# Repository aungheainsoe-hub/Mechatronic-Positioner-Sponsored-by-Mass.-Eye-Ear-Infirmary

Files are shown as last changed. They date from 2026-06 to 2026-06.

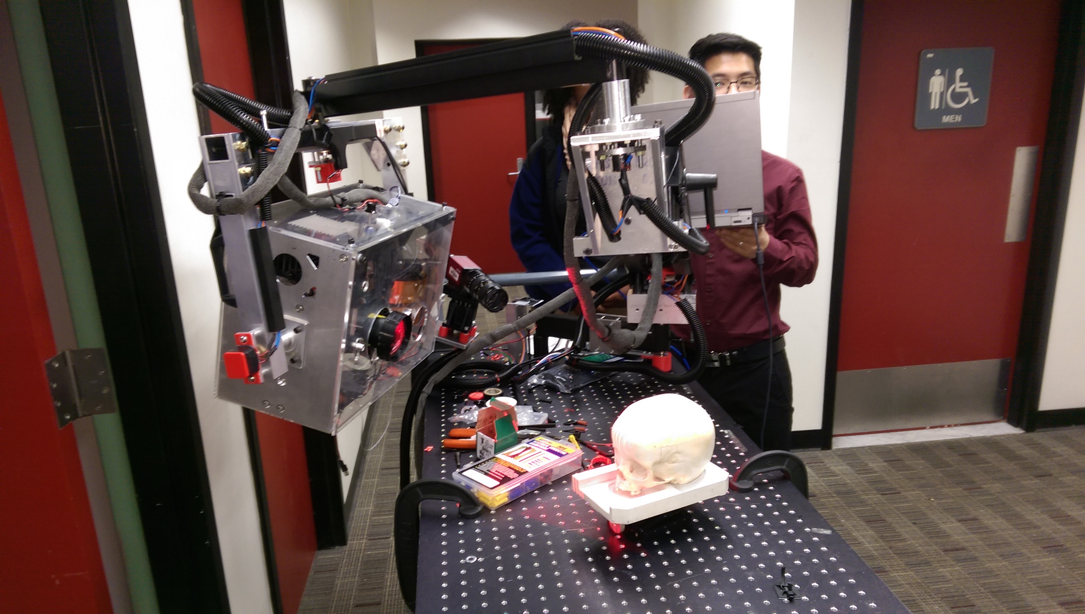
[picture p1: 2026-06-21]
IMAG0439.jpg

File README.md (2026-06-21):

# Mechatronic-Positioner-Sponsored-by-Mass.-Eye-Ear-Infirmary
Designing to implement a new generation of Mechatronic positioning system for a shape measurements device (fringe projector) used for medical and industrial applications.

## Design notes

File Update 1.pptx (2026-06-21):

## Repackaging of Fringe Projector

Design Group 1
ME 4320

## List of components

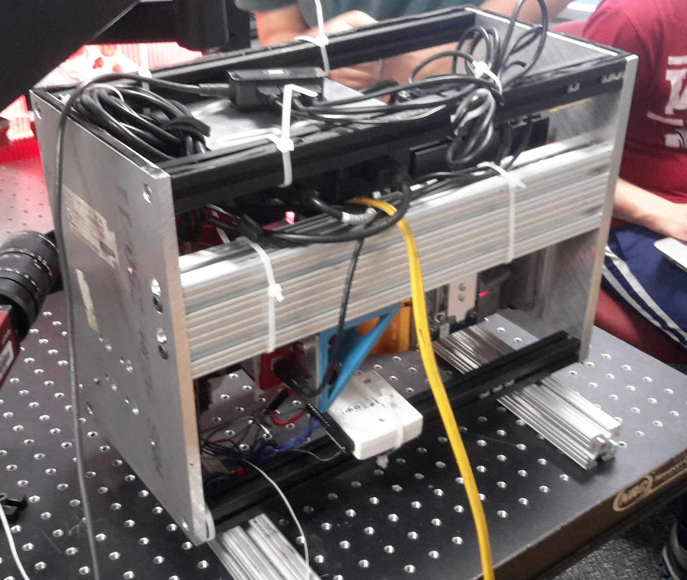
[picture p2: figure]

- Side Panels Al 6061 (8”x12”x.375”) = 3.51 lb x 2 = 7.02 lb
- Beam Al 8020 Double wide (1.5”x3”x16”) = 3.23 lb
- Black 80/20 Al frame beams (1”x1”x16”) = 1.37 lb x 4 = 5.48 lb
- Cables, power adapters, wiring = est.6 lb
- Fringe Projector (Structured light projection package = 1800 g = 3.97 lb
Total weight = approx. 26.8 lb
- Camera = 250 g =.55 lb

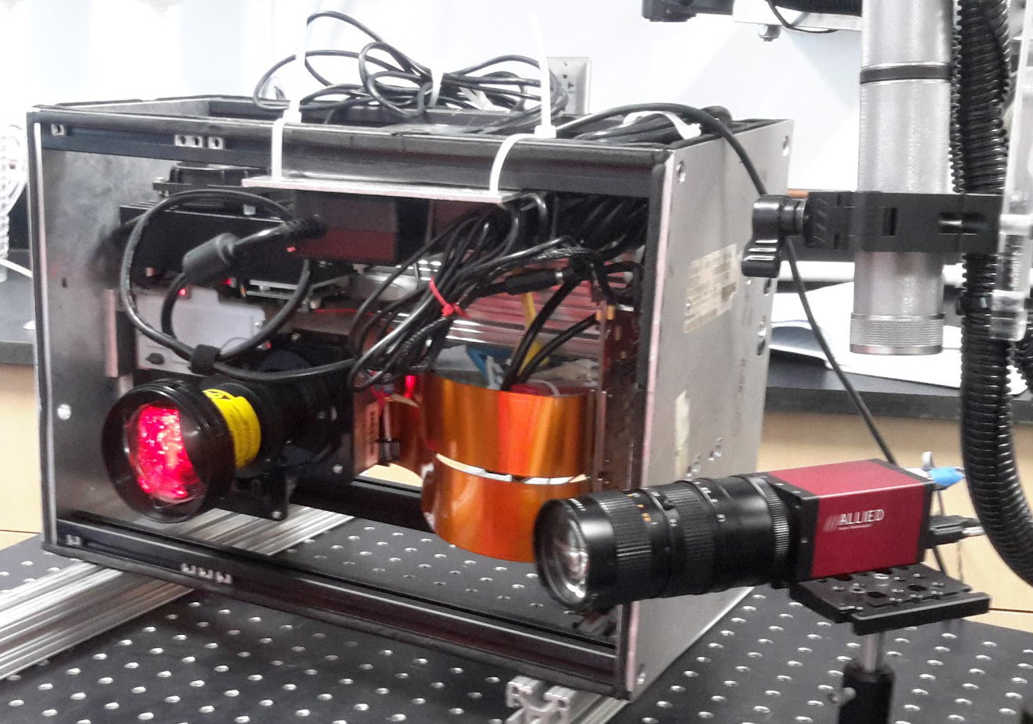
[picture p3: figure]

## Potential Layout Changes

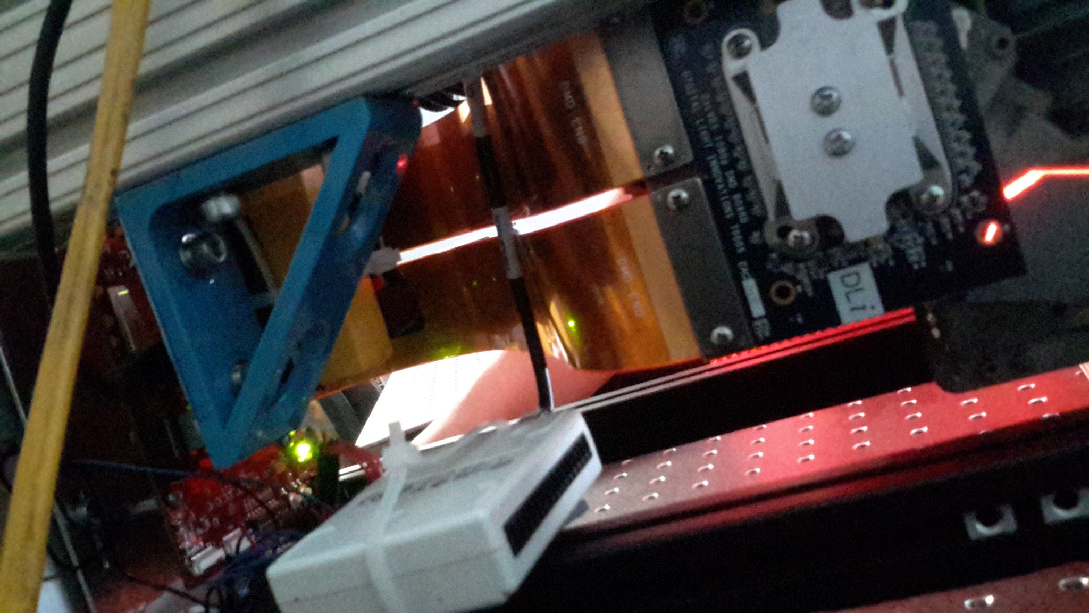
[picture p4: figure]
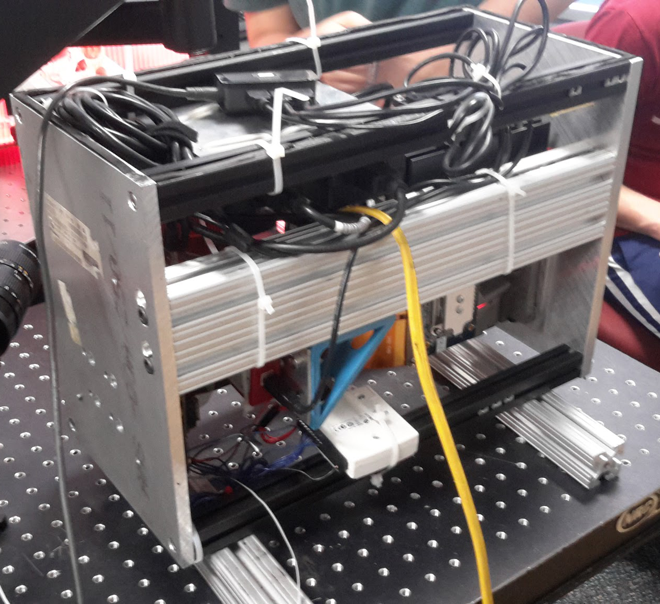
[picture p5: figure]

Weight Reduction
- Thinner plates/Milled plates: up to 4.68 lb
- Remove double wide 80/20: 3.23 lb
- Replace double wide 80/20 with 1” square beam: 1.86 lb

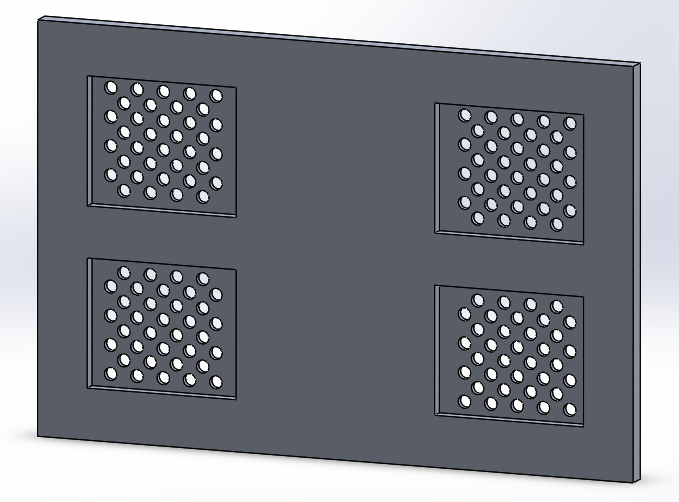
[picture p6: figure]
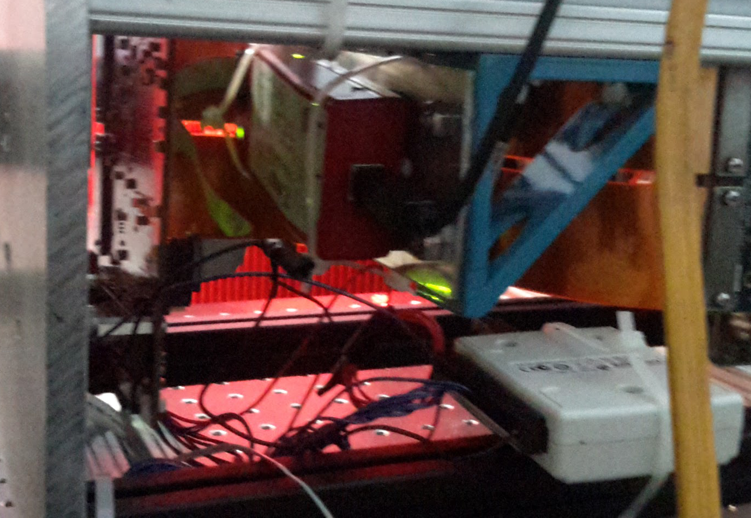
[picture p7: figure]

## Cable Management

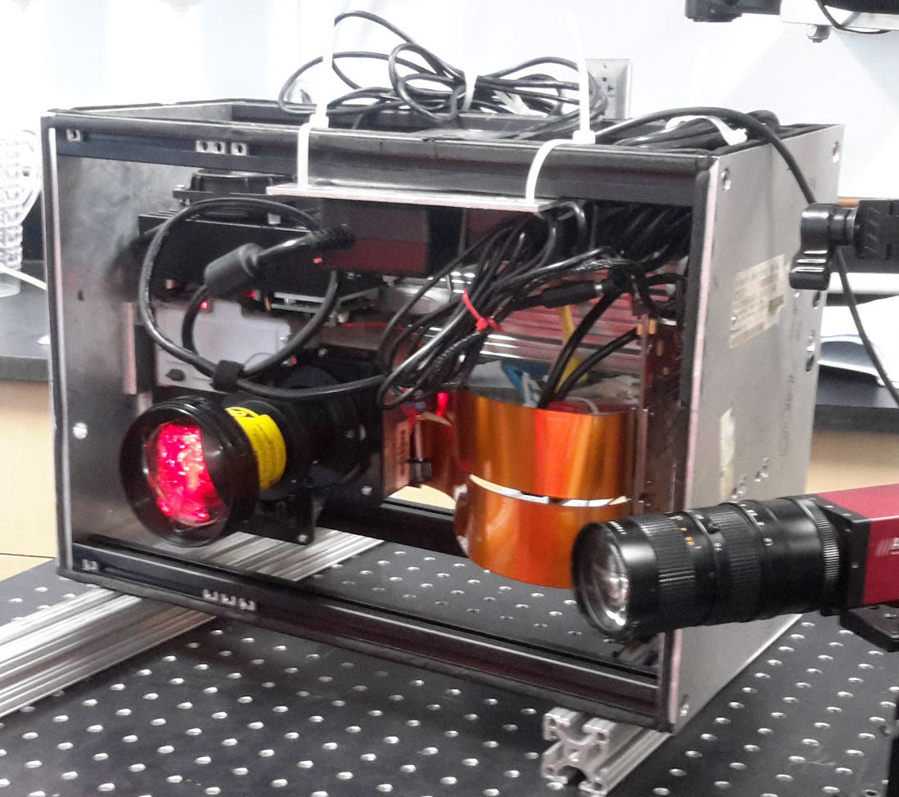
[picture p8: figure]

Weight Reduction
- Removing/relocating cables: up to 5 lb at end effector

## Positioning Camera

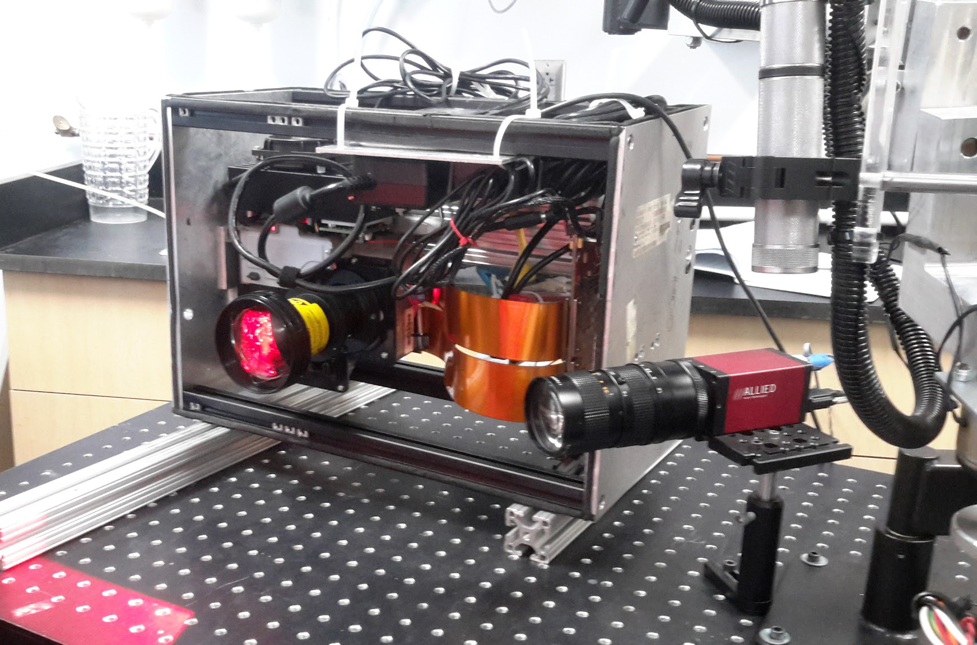
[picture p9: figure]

Weight Reduction
- Adds weight from camera: .55 lb

## Potential Added Weight

- Handles: .43 lb per handle
- Acrylic casing
  - Top and bottom panels: 2.18 lb per panel .375 thickness, 1.09 lb per panel 3/16” thickness
  - Back panel: 3.27 lb for .325” thickness, 1.63 lb for 3/16” thickness,
- Camera: .55 lb
- Sensors: unknown at this point

## Overall Estimates

- Expect to reduce weight by approximately 5 pounds
- Optimistically, 7-8 pounds

## Resources

WPI paper on the original packaging - https://www.wpi.edu/Pubs/ETD/Available/etd-082611-133113/unrestricted/Zervas.pdf
Steel handle used - http://www.knobdeals.com/product/391/knob-deals-1110-3-12quot-89mm-steel-bar-pull-satin-nickel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

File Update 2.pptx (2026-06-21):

## UPDATE

Design & Analysis 1

## Updates From Yesterday

- After changing the plates to 1/8" Garolite G-10 Only reduced the weight of the frame by 4lbs
- Wiring can be held adjacent to the C-bracket as seen from Design & Analysis #2
- At this point we are not sure how easily manufacture the material is and believe we should proceed with the current aluminum and polycarbonate set up

## Angle and Arm Length

- The angle α between the camera and projector can be calculated using sine law
- The angle β can either be read directly off of the mounting plate
- Camera support arm should be approximately 27.5” based off of our calculation of D.cp
- Allows for a maximum angle of 45 degrees

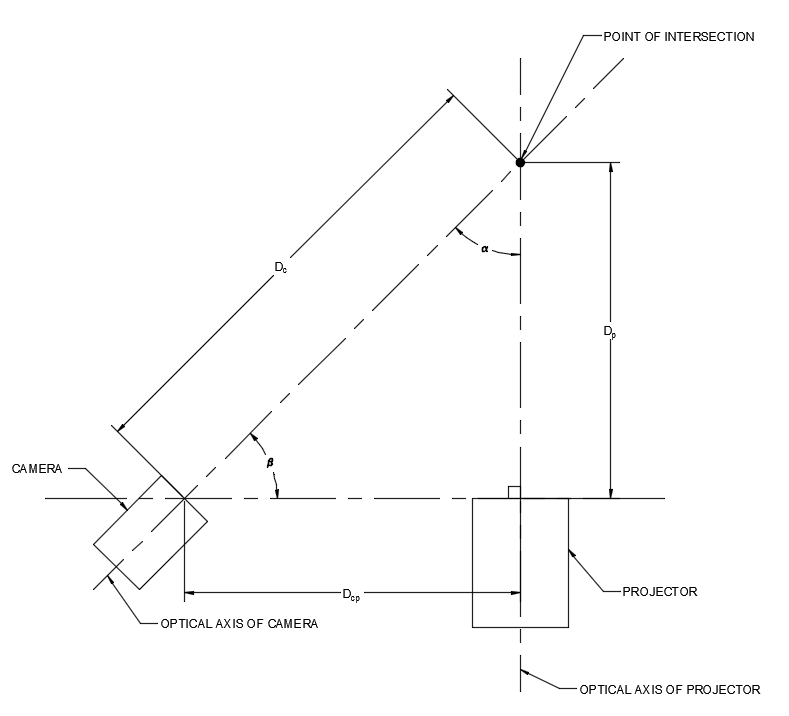
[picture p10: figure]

## Future Work

- Add Laser pointer into the assembly
- Finalize Connection Points to Arm
- Finalize housings for mini-DAQ box and Red box connecting to the DLP board
- Mount Distance Sensor

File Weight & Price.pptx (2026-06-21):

## Design & Analysis #1

## Weight of Components

QTY | Component | Weight (kg)
1 | Side Plate - Projector Side | 0.99
1 | Side Plate - Board Side | 0.73
1 | Top Plate | 0.32
1 | Bottom Plate | 0.33
1 | Fan | 0.01
1 | Fringe Projector & Board | 1.8
4 | 80/20 Support Beams | 1.24
1 | Camera Support Beam | 0.56
1 | Front Plate | 0.49

## Weight of Components: Continued

QTY | Component | Weight (kg)
1 | Camera | 0.25
1 | Lens | ~0.45
1 | Pro1 Manual Angle | 0.29
2 | Linear Carriage | Not Listed
2 | Hand Brake | Not Listed
1 | Mounting Plate | 0.14
N/A | Wiring & MISC | ~2.75
2 | Handes | Not Listed
Total | | 10.35 (~22.82-lbs)

## Price of Components

Component | Price (USD $)
Pro1 | $318
Mounting Plate | Part of Current Configuration
Camera Mounting Arm | $12.85
Handles | $12.80
Linear Carriage | $92.32
Hand Brakes | $21.54
Sticker Ruler | $10.56
80/20 Support Beams | Part of current configuration
Aluminum Sheets | $51.82

## Price of Components: Continued

Component | Price (USD $)
Poly Carbonate Sheet | $115.46
Total | $635.35

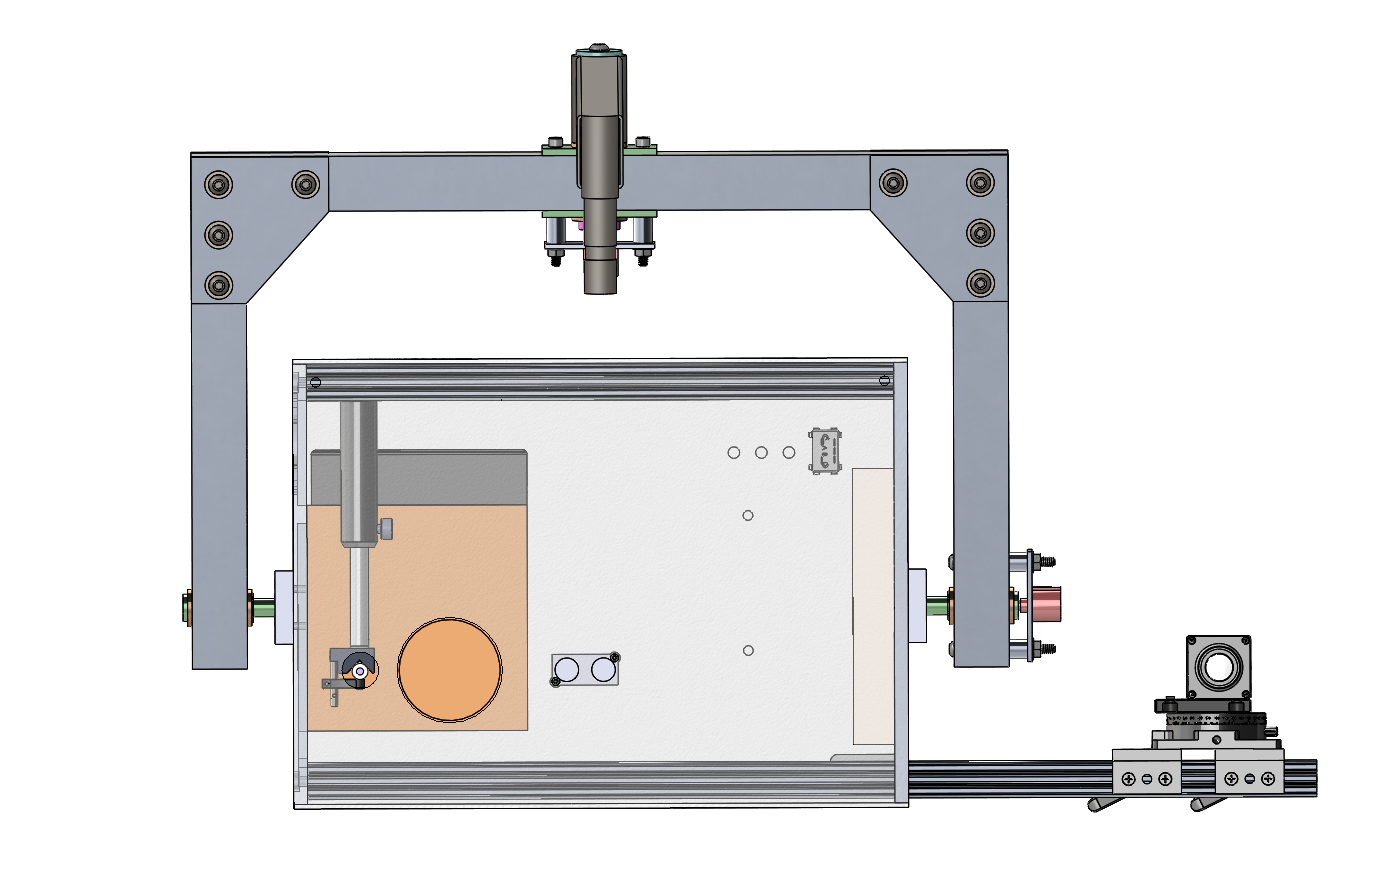
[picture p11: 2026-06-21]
Projector_Airflow.PNG

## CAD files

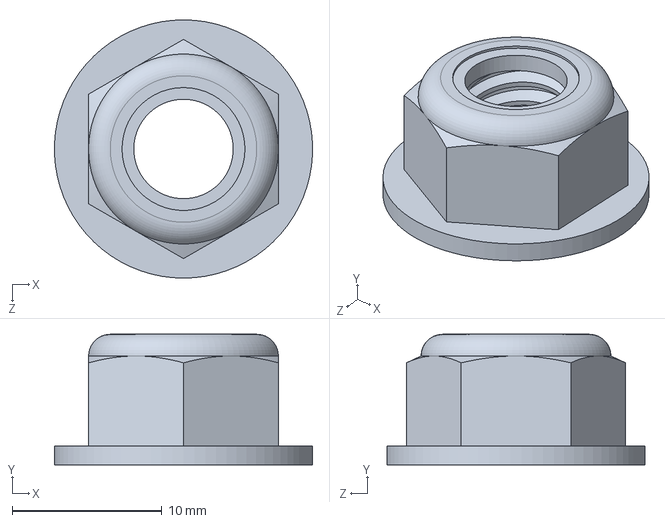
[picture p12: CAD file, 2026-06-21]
MM_92018A320_0.3125-18_Flanged-Locknut.SLDPRT
17.3 x 8.73 x 17.3 mm

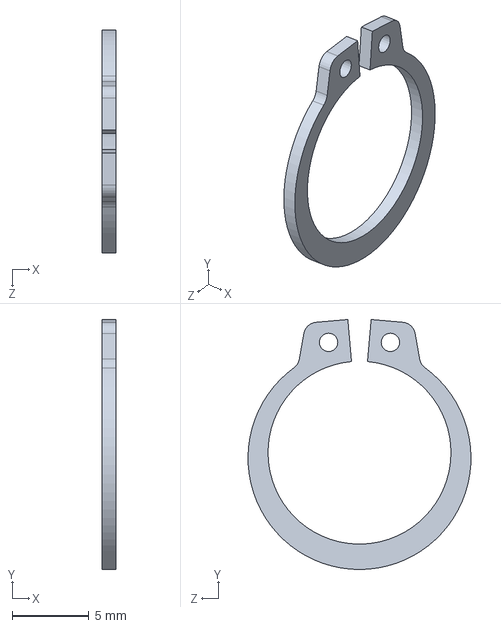
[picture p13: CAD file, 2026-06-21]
MM_96363A553_0.5in_External-Retaining-Ring.SLDPRT
0.889 x 16.2 x 14.5 mm

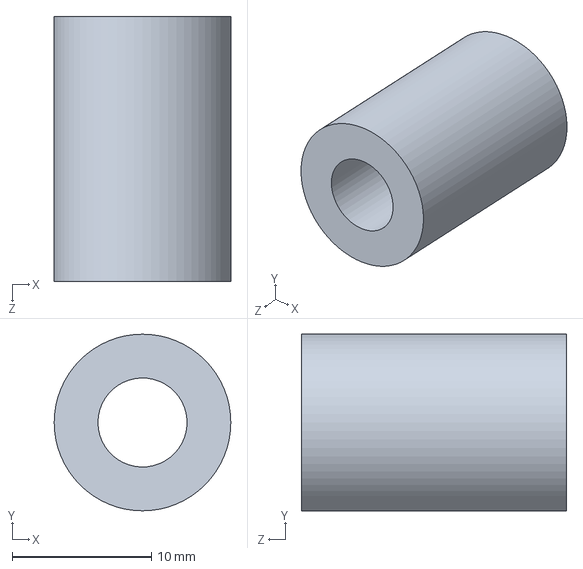
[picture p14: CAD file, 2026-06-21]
MM_92510A767_0.252IDx0.5ODx0.75L_AL-Spacer_Round.SLDPRT
12.7 x 12.7 x 19.1 mm

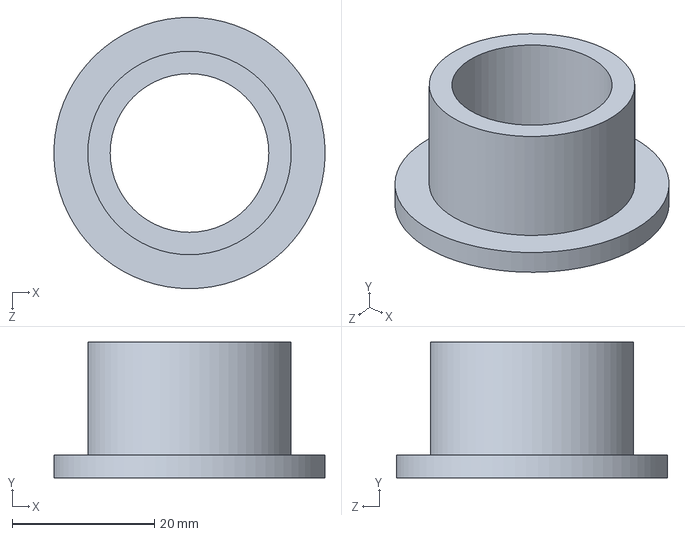
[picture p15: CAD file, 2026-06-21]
MM_6338K479_0.875IDx1.125ODx0.75L_Bushing.SLDPRT
38.1 x 19.1 x 38.1 mm

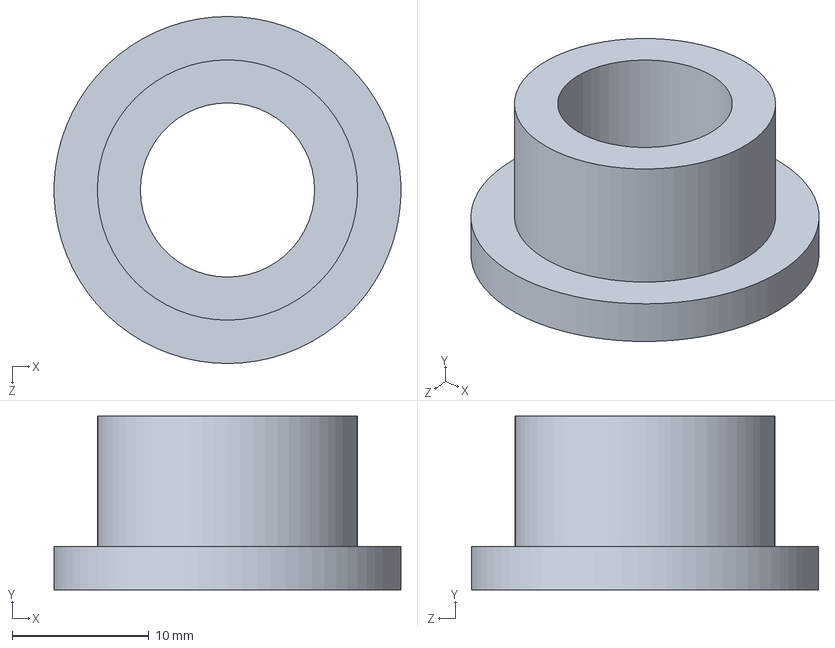
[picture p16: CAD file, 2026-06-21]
MM_6338K422_0.502IDx0.75ODx0.5L_Flanged-Sleeve-Bushing.SLDPRT
25.4 x 12.7 x 25.4 mm

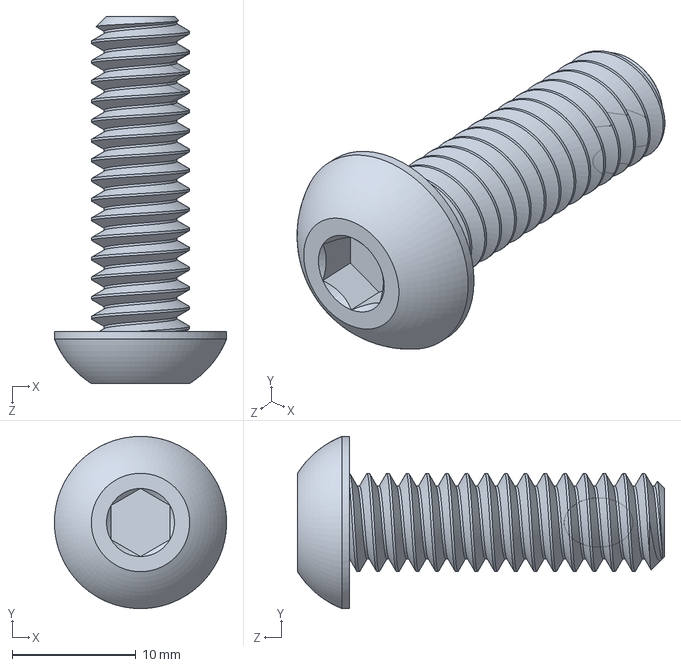
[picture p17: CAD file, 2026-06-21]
MM_93310A583_0.3125-18x1L_Thread-Locking_Button-Head.SLDPRT
13.9 x 13.9 x 29.6 mm

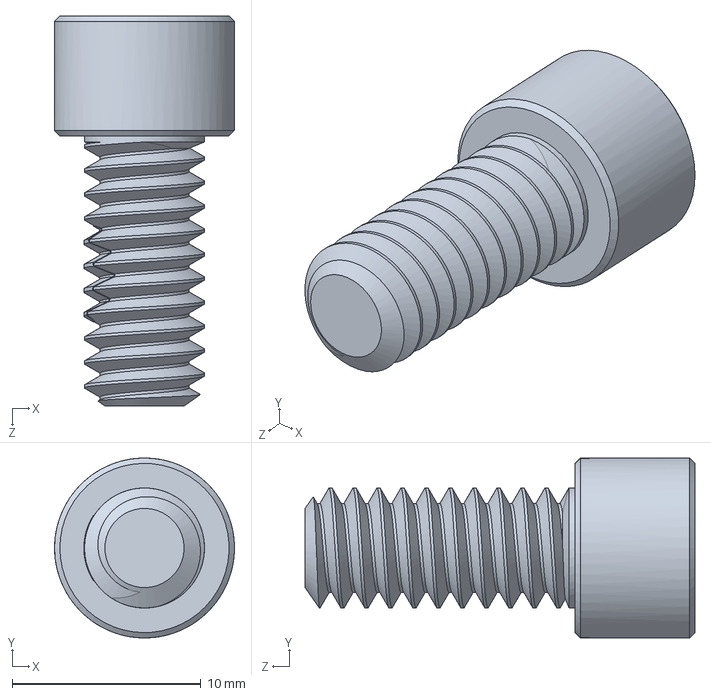
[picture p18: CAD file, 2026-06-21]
MM_91205A538_0.25-20x0.5625_Thread-Locking_Socket-Cap.SLDPRT
9.53 x 9.52 x 20.6 mm

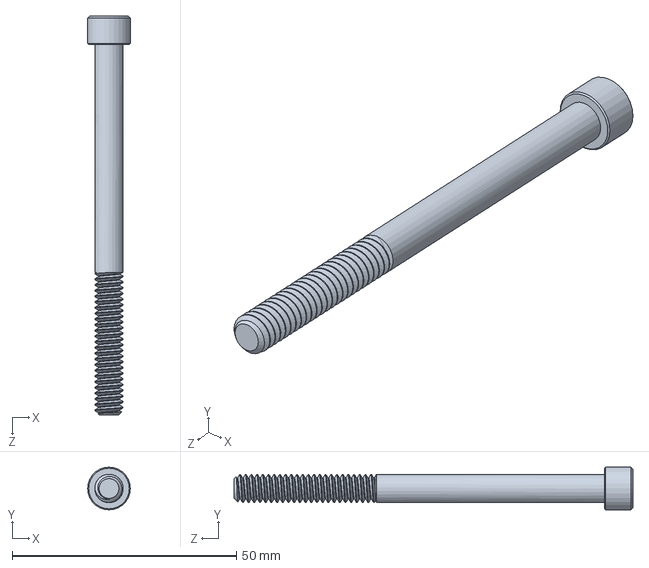
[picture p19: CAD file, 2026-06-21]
MM_92196A555_0.25-20x3.25L_Socket-Cap.SLDPRT
9.53 x 9.53 x 88.9 mm

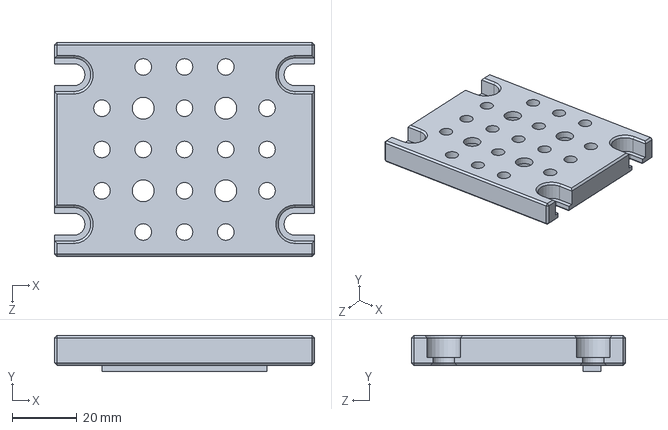
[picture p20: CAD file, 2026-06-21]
Mounting_Plate.SLDPRT
80.0 x 11.2 x 66.0 mm

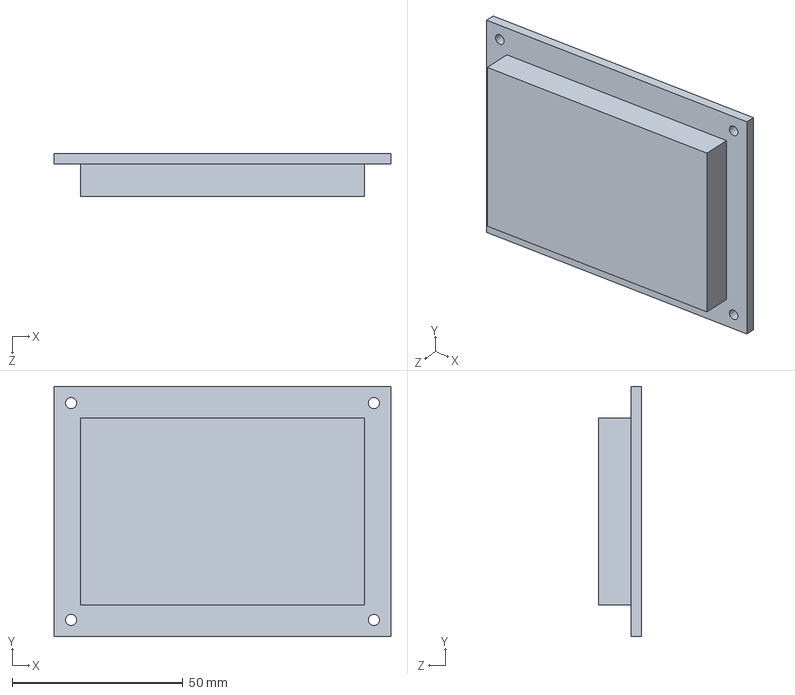
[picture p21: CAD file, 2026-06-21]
MOCK_BreadBoard.SLDPRT
98.7 x 73.2 x 12.7 mm

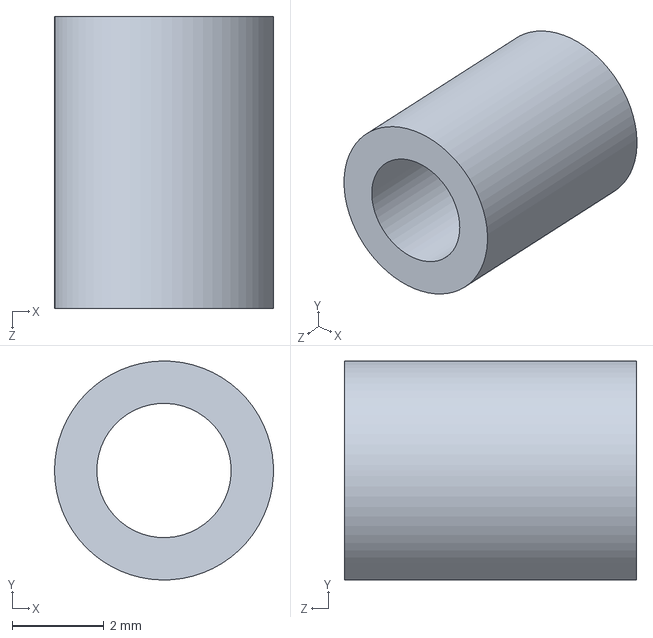
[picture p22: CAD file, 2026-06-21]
Nylon_Standoff_94639A706.SLDPRT
4.76 x 4.76 x 6.35 mm

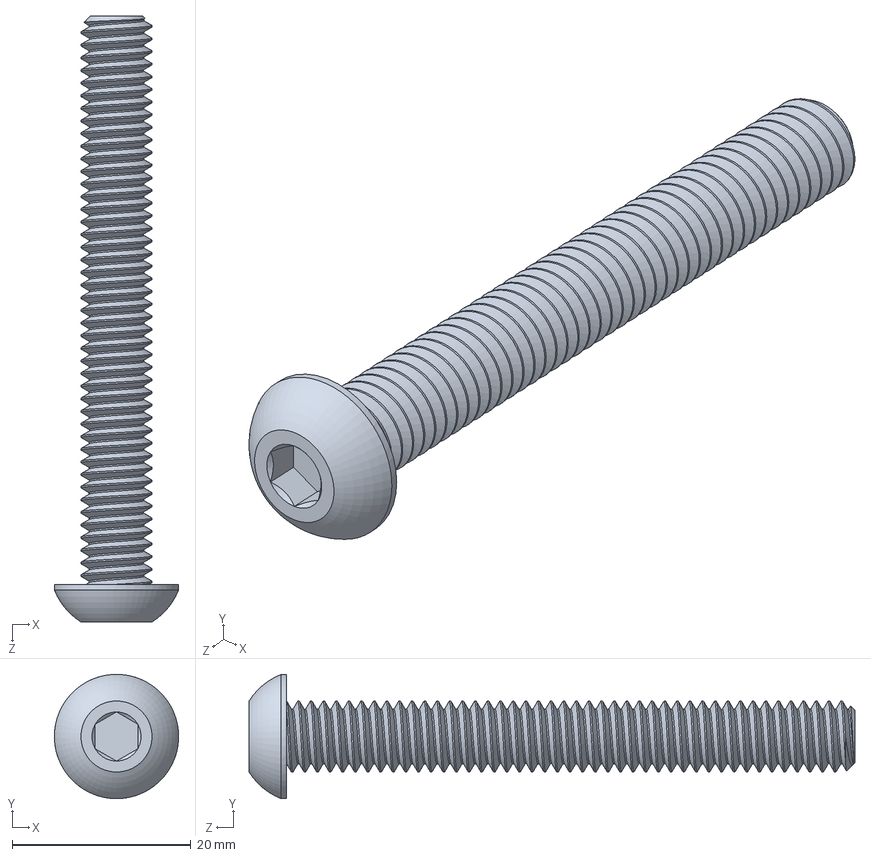
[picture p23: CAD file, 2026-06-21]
MM_91255A592_0.3125-18x2.5in_Button-Head.SLDPRT
13.9 x 13.9 x 67.7 mm

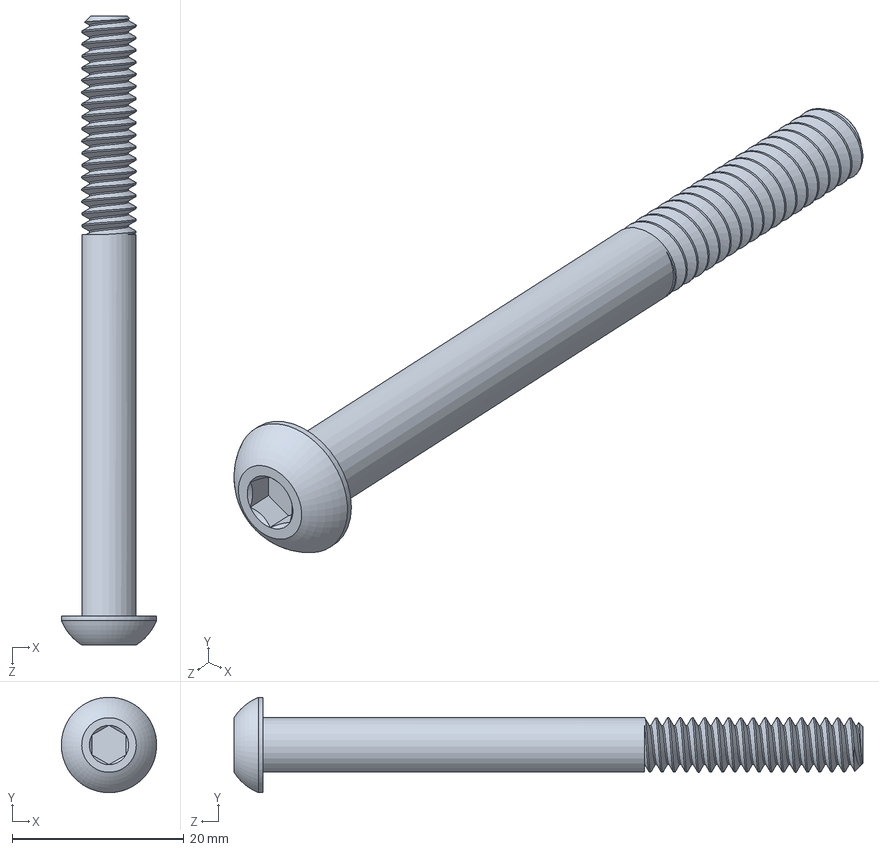
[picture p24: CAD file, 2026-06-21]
MM_98164A465_0.25-20x2.75L_Button-Head.SLDPRT
11.1 x 11.1 x 73.2 mm

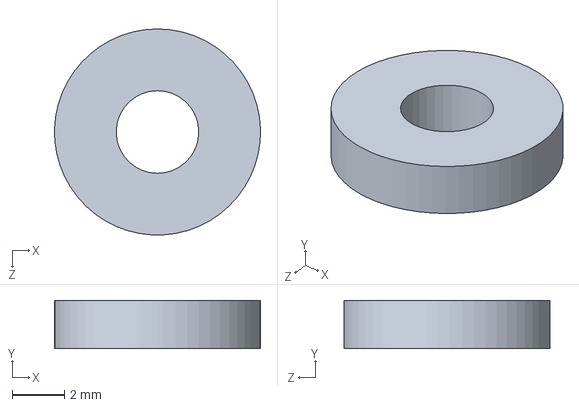
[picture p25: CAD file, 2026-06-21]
Nylon_Washer_92150A103.SLDPRT
7.92 x 1.85 x 7.92 mm

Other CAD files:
No. 8 Washer.SLDPRT
MM_92140A116_0.344x1.25_Flat-Washer.SLDPRT
MM_92150A137_0.515IDx0.875OD_Plastic-Washer.SLDPRT
MM_94902A101_0.25-20_Flange-Nut.SLDPRT
MM_90251A576_0.3125-18x0.375_Thread-Locking_Set-Screw.SLDPRT
MM_92141A030_0.3125_Flat-Washer.SLDPRT
